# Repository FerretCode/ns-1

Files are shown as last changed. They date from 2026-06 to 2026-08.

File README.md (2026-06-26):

# ns-1

Lo-fi first hardware sampler

# Overview

- Teensy 4.1 based
- 16 Cherry MX switch pads
- 1/4" line in/out
- 3.5mm headphone jack
- 3 rotary encoders for sample editing
- 4 potentiometers for FX control
- Slider for master track volume control
- MicroSD card for loading and exporting samples
- Per-pad looping
- Resampling
- Sampling over USB-C

## Architecture

- The core audio processing functionality is provided by the Teensy 4.1 and its accompanying audio shield (Rev. D)
- Adafruit 1.9" TFT display over SPI
- Line in/out, headphone jack is handled by the audio shield, with volume control in firmware

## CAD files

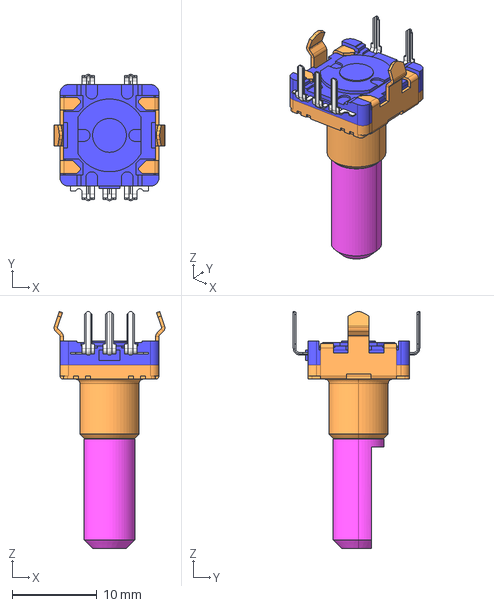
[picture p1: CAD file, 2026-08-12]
hardware/models/ec11e15204a3.stp
13.1 x 15.0 x 28.0 mm

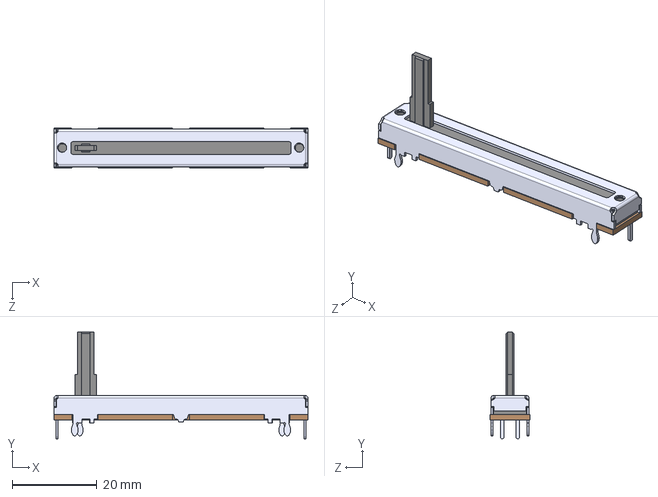
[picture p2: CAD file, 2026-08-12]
hardware/models/PTA4543-2015CPB102.STEP
60.0 x 25.2 x 9.40 mm

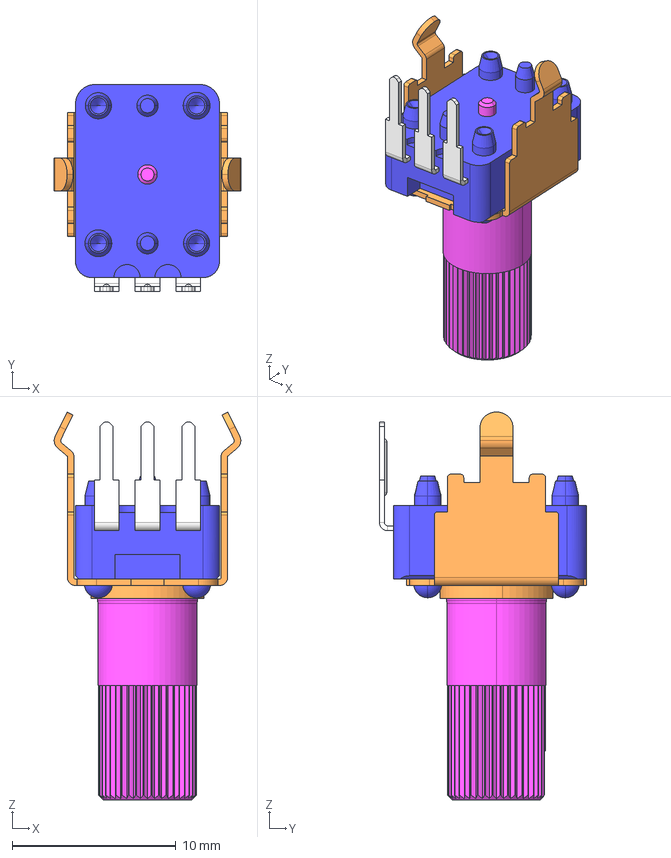
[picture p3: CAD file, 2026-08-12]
hardware/models/rk09k1130a5r.stp
11.4 x 12.7 x 23.7 mm

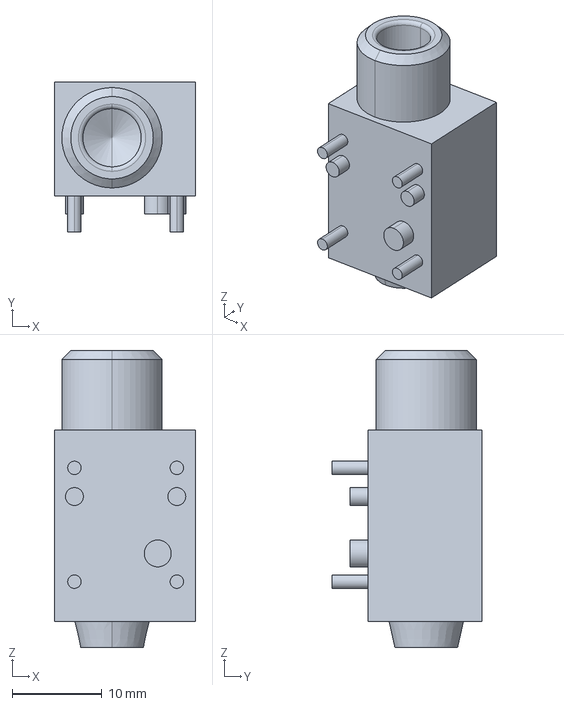
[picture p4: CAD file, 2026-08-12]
hardware/models/nrj4hf-2.stp
15.8 x 16.7 x 33.1 mm

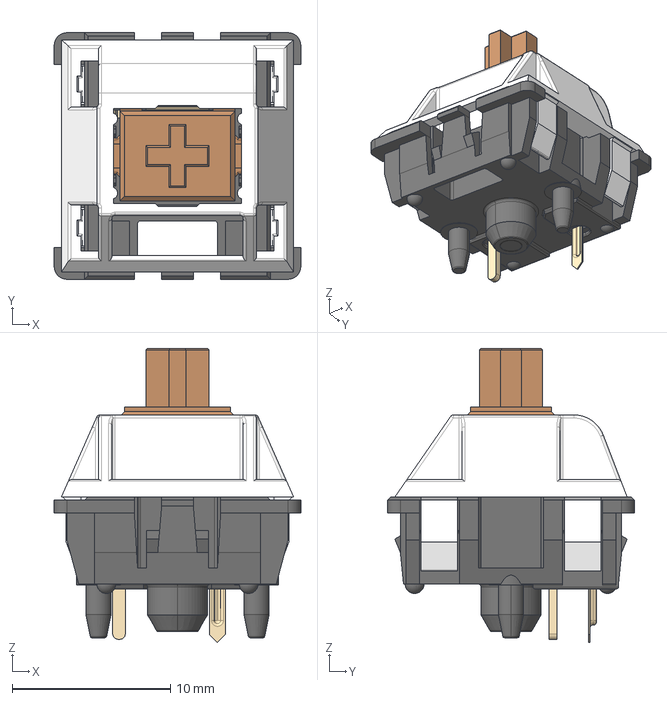
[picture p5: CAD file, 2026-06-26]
hardware/models/MX_PCB.step
15.6 x 15.6 x 18.6 mm

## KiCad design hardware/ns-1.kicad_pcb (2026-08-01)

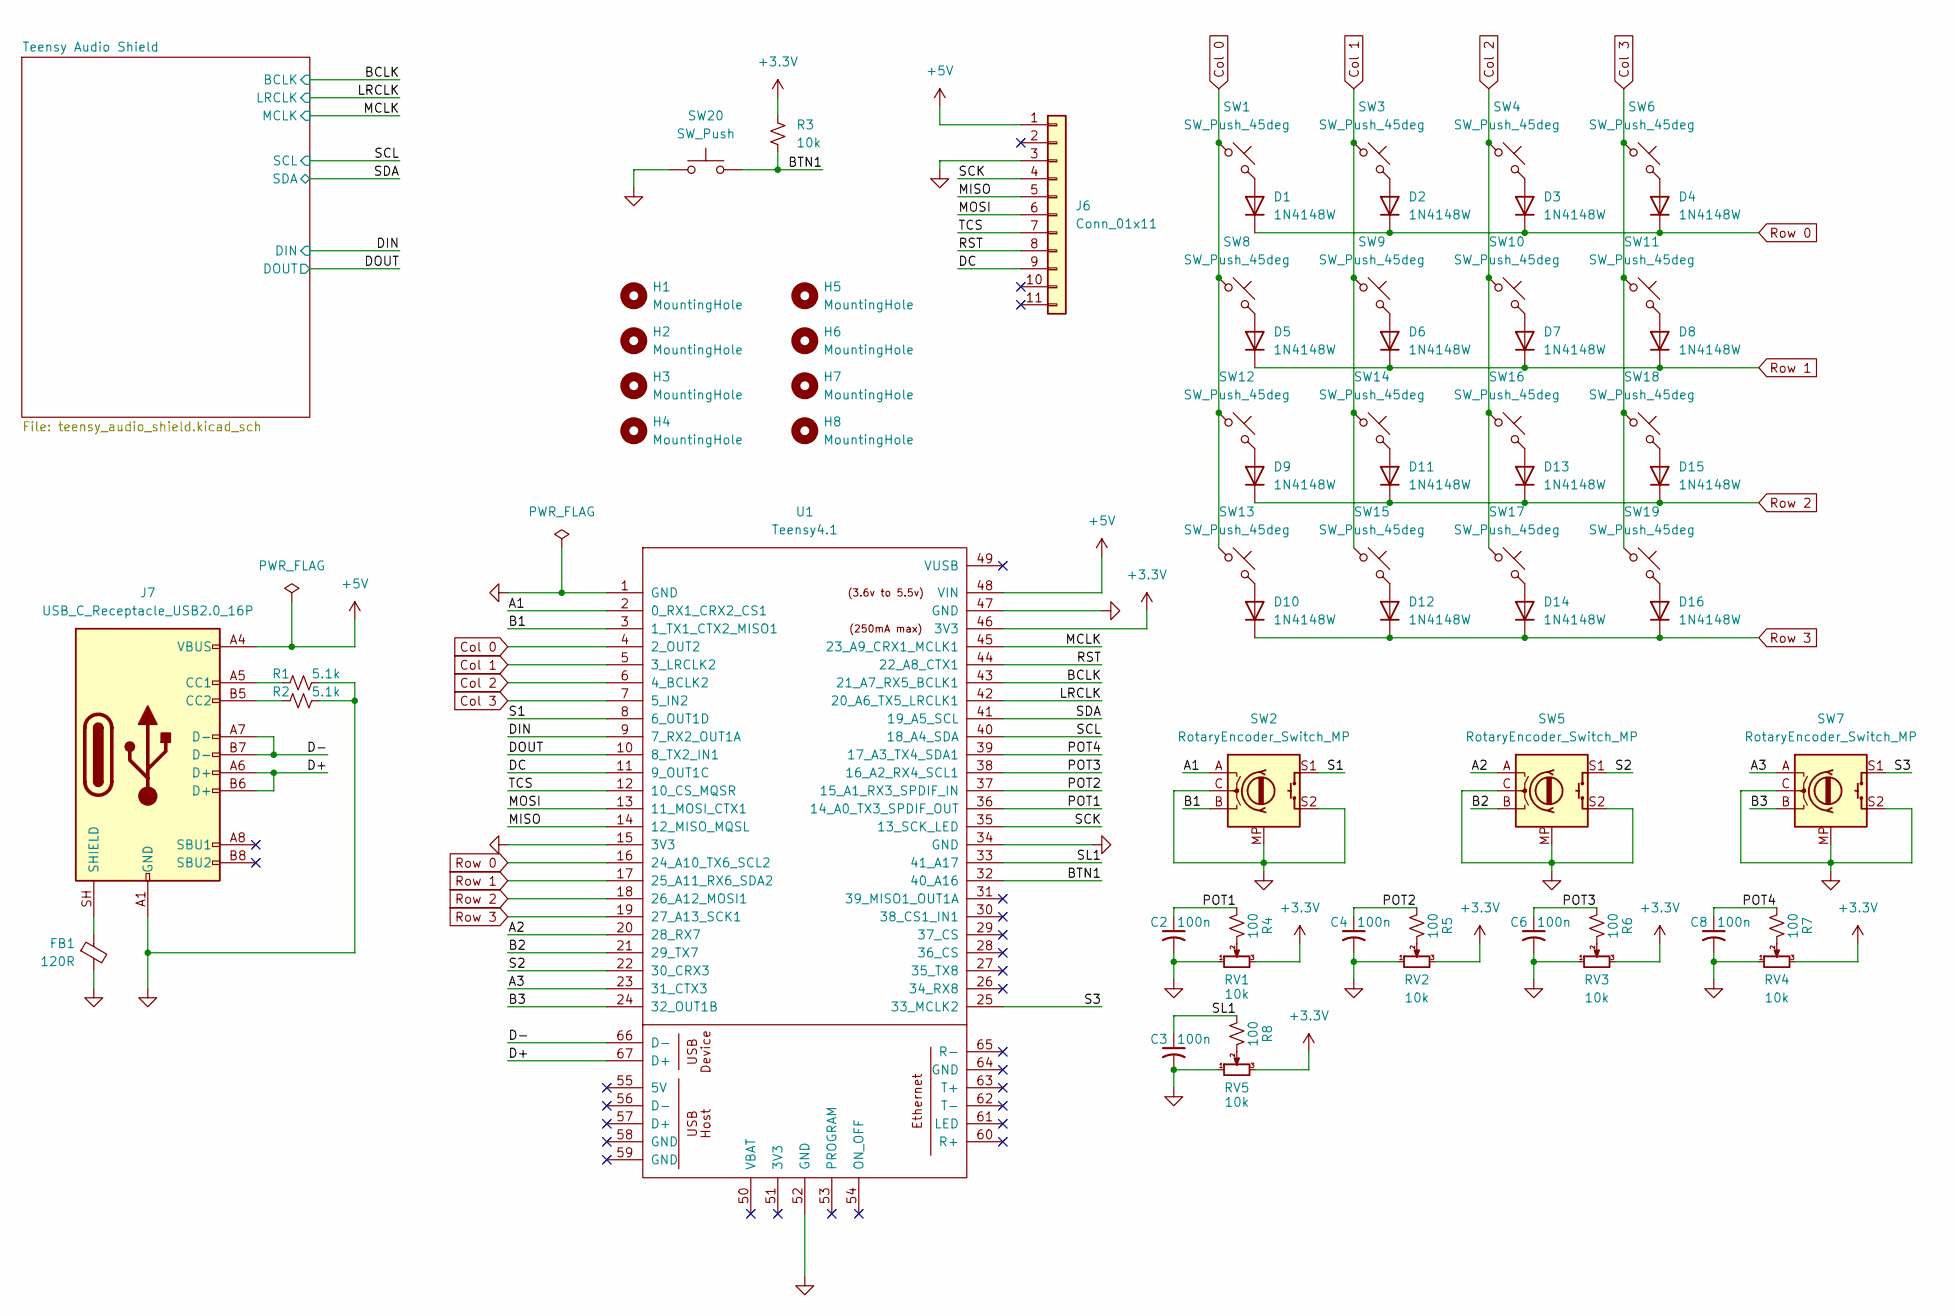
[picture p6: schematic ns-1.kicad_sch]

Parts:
C2, C3, C4, C6: 100n; C_0402_1005Metric; LCSC PN C22435941
C8: 100n; C_0402_1005Metric
D1, D2, D3, D4, D5, D6, D7, D8, D9, D10, D11, D12, D13, D14, D15, D16: 1N4148W; D_SOD-123; LCSC PN C917030
FB1: 120R; L_0805_2012Metric; LCSC PN C2943443
H1, H2, H3, H4: MountingHole; MountingHole_2.5mm
H5, H6, H7, H8: MountingHole; MountingHole_4.5mm
J6: Conn_01x11; PinHeader_1x11_P2.54mm_Vertical
J7: USB_C_Receptacle_USB2.0_16P; USB_C_Receptacle_HRO_TYPE-C-31-M-12; LCSC PN C3197899
R1, R2: 5.1k; R_0603_1608Metric; LCSC PN C2906874
R3: 10k; R_0603_1608Metric; LCSC PN C317926
R4, R5, R6, R7, R8: 100; R_0603_1608Metric; LCSC PN C122970
RV1, RV2, RV3, RV4: 10k; Potentiometer_Alps_RK09K_Single_Vertical
RV5: 10k; Potentiometer_Bourns_PTA4543_Single_Slide
SW1, SW3, SW4, SW6, SW8, SW9, SW10, SW11, SW12, SW13, SW14, SW15, SW16, SW17, SW18, SW19: SW_Push_45deg; SW_Cherry_MX_1.00u_PCB
SW2, SW5, SW7: RotaryEncoder_Switch_MP; RotaryEncoder_Alps_EC11E-Switch_Vertical_H20mm
SW20: SW_Push; SW_Cherry_MX_1.00u_PCB
U1: Teensy4.1; Teensy41

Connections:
+3.3V: R3.1, RV1.3, RV2.3, RV3.3, RV4.3, RV5.3, U1.46 (3V3); also elsewhere on the board
+5V: J6.1, J7.A4 (VBUS), J7.A9 (VBUS), J7.B4 (VBUS), J7.B9 (VBUS), U1.48 (VIN)
/A1: SW2.A, U1.2 (0_RX1_CRX2_CS1)
/A2: SW5.A, U1.20 (28_RX7)
/A3: SW7.A, U1.23 (31_CTX3)
/B1: SW2.B, U1.3 (1_TX1_CTX2_MISO1)
/B2: SW5.B, U1.21 (29_TX7)
/B3: SW7.B, U1.24 (32_OUT1B)
/BCLK: U1.43 (21_A7_RX5_BCLK1); also elsewhere on the board
/BTN1: R3.2, SW20.2, U1.32 (40_A16)
/D+: J7.A6 (D+), J7.B6 (D+), U1.67 (D+)
/D-: J7.A7 (D-), J7.B7 (D-), U1.66 (D-)
/DC: J6.9, U1.11 (9_OUT1C)
/DIN: U1.9 (7_RX2_OUT1A); also elsewhere on the board
/DOUT: U1.10 (8_TX2_IN1); also elsewhere on the board
/LRCLK: U1.42 (20_A6_TX5_LRCLK1); also elsewhere on the board
/MCLK: U1.45 (23_A9_CRX1_MCLK1); also elsewhere on the board
/MISO: J6.5, U1.14 (12_MISO_MQSL)
/MOSI: J6.6, U1.13 (11_MOSI_CTX1)
/POT1: C2.1, R4.2, U1.36 (14_A0_TX3_SPDIF_OUT)
/POT2: C4.1, R5.2, U1.37 (15_A1_RX3_SPDIF_IN)
/POT3: C6.1, R6.2, U1.38 (16_A2_RX4_SCL1)
/POT4: C8.1, R7.2, U1.39 (17_A3_TX4_SDA1)
/RST: J6.8, U1.44 (22_A8_CTX1)
/S1: SW2.S1, U1.8 (6_OUT1D)
/S2: SW5.S1, U1.22 (30_CRX3)
/S3: SW7.S1, U1.25 (33_MCLK2)
/SCK: J6.4, U1.35 (13_SCK_LED)
/SCL: U1.40 (18_A4_SDA); also elsewhere on the board
/SDA: U1.41 (19_A5_SCL); also elsewhere on the board
/SL1: C3.1, R8.2, U1.33 (41_A17)
/TCS: J6.7, U1.12 (10_CS_MQSR)
Col 0: SW1.1, SW8.1, SW12.1, SW13.1, U1.4 (2_OUT2)
Col 1: SW3.1, SW9.1, SW14.1, SW15.1, U1.5 (3_LRCLK2)
Col 2: SW4.1, SW10.1, SW16.1, SW17.1, U1.6 (4_BCLK2)
Col 3: SW6.1, SW11.1, SW18.1, SW19.1, U1.7 (5_IN2)
GND: C2.2, C3.2, C4.2, C6.2, C8.2, FB1.2, J6.3, J7.A1 (GND), J7.A12 (GND), J7.B1 (GND), J7.B12 (GND), R1.2, R2.2, RV1.1, RV2.1, RV3.1, RV4.1, RV5.1, SW2.C, SW2.MP, SW2.S2, SW5.C, SW5.MP, SW5.S2, SW7.C, SW7.MP, SW7.S2, SW20.1, U1.1 (GND), U1.15 (3V3), U1.34 (GND), U1.47 (GND), U1.52 (GND); also elsewhere on the board
unnamed: D1.2 (A), SW1.2
unnamed: D2.2 (A), SW3.2
unnamed: D3.2 (A), SW4.2
unnamed: D4.2 (A), SW6.2
unnamed: D5.2 (A), SW8.2
unnamed: D6.2 (A), SW9.2
unnamed: D7.2 (A), SW10.2
unnamed: D8.2 (A), SW11.2
unnamed: D9.2 (A), SW12.2
unnamed: D10.2 (A), SW13.2
unnamed: D11.2 (A), SW14.2
unnamed: D12.2 (A), SW15.2
unnamed: D13.2 (A), SW16.2
unnamed: D14.2 (A), SW17.2
unnamed: D15.2 (A), SW18.2
unnamed: D16.2 (A), SW19.2
unnamed: J7.A5 (CC1), R1.1
unnamed: J7.B5 (CC2), R2.1
unnamed: FB1.1, J7.SH (SHIELD)
unnamed: R4.1, RV1.2
unnamed: R5.1, RV2.2
unnamed: R6.1, RV3.2
unnamed: R7.1, RV4.2
unnamed: R8.1, RV5.2
Row 0: D1.1 (K), D2.1 (K), D3.1 (K), D4.1 (K), U1.16 (24_A10_TX6_SCL2)
Row 1: D5.1 (K), D6.1 (K), D7.1 (K), D8.1 (K), U1.17 (25_A11_RX6_SDA2)
Row 2: D9.1 (K), D11.1 (K), D13.1 (K), D15.1 (K), U1.18 (26_A12_MOSI1)
Row 3: D10.1 (K), D12.1 (K), D14.1 (K), D16.1 (K), U1.19 (27_A13_SCK1)

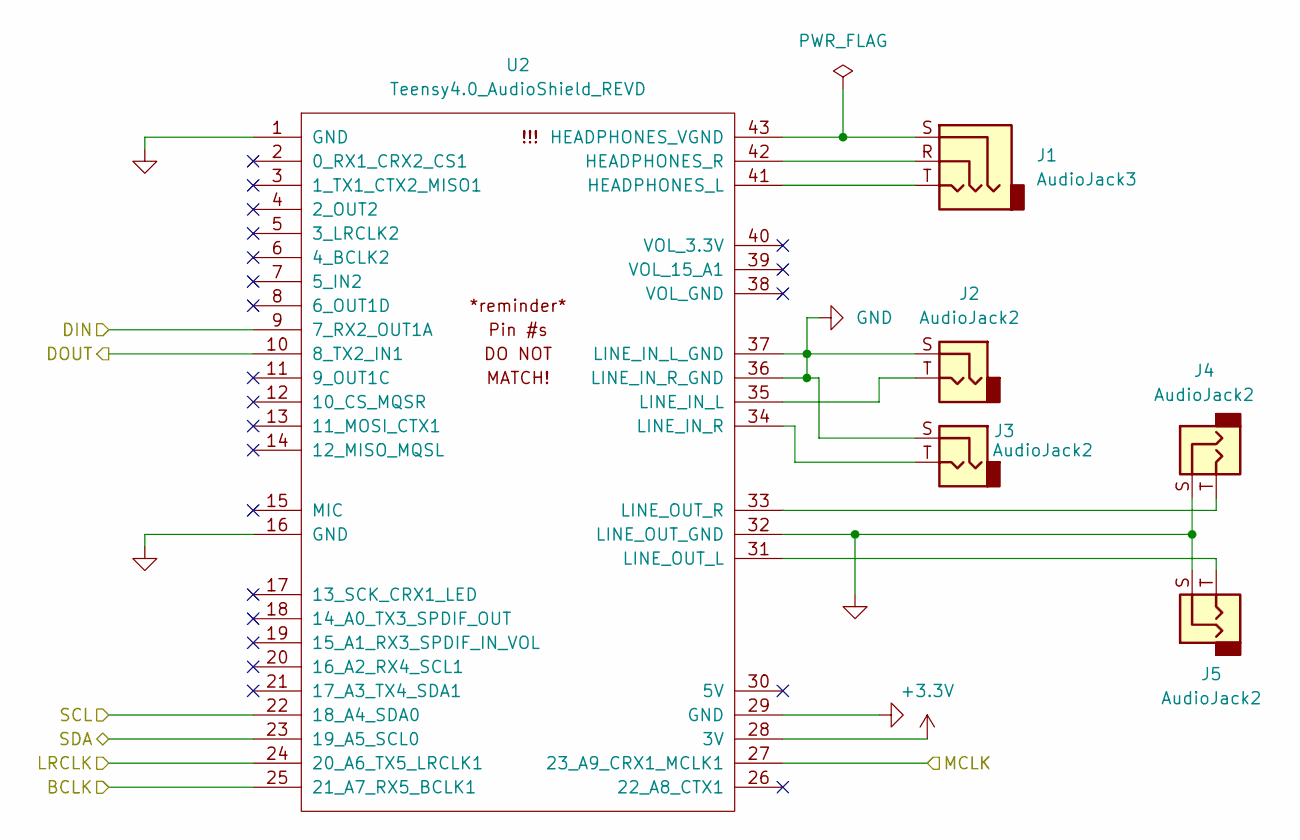
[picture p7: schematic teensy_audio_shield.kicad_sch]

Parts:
J1: AudioJack3; Jack_3.5mm_CUI_SJ1-3533NG_Horizontal
J2, J3, J4, J5: AudioJack2; Jack_6.35mm_Neutrik_NRJ4HF_Horizontal
U2: Teensy4.0_AudioShield_REVD; 4.0audioshield

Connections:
+3.3V: U2.28 (3V); also elsewhere on the board
/BCLK: U2.25 (21_A7_RX5_BCLK1); also elsewhere on the board
/DIN: U2.9 (7_RX2_OUT1A); also elsewhere on the board
/DOUT: U2.10 (8_TX2_IN1); also elsewhere on the board
/LRCLK: U2.24 (20_A6_TX5_LRCLK1); also elsewhere on the board
/MCLK: U2.27 (23_A9_CRX1_MCLK1); also elsewhere on the board
/SCL: U2.22 (18_A4_SDA0); also elsewhere on the board
/SDA: U2.23 (19_A5_SCL0); also elsewhere on the board
GND: J2.S, J3.S, J4.S, J5.S, U2.1 (GND), U2.16 (GND), U2.29 (GND), U2.32 (LINE_OUT_GND), U2.36 (LINE_IN_R_GND), U2.37 (LINE_IN_L_GND); also elsewhere on the board
unnamed: J1.T, U2.41 (HEADPHONES_L)
unnamed: J1.R, U2.42 (HEADPHONES_R)
unnamed: J1.S, U2.43 (HEADPHONES_VGND)
unnamed: J2.T, U2.35 (LINE_IN_L)
unnamed: J3.T, U2.34 (LINE_IN_R)
unnamed: J5.T, U2.31 (LINE_OUT_L)
unnamed: J4.T, U2.33 (LINE_OUT_R)

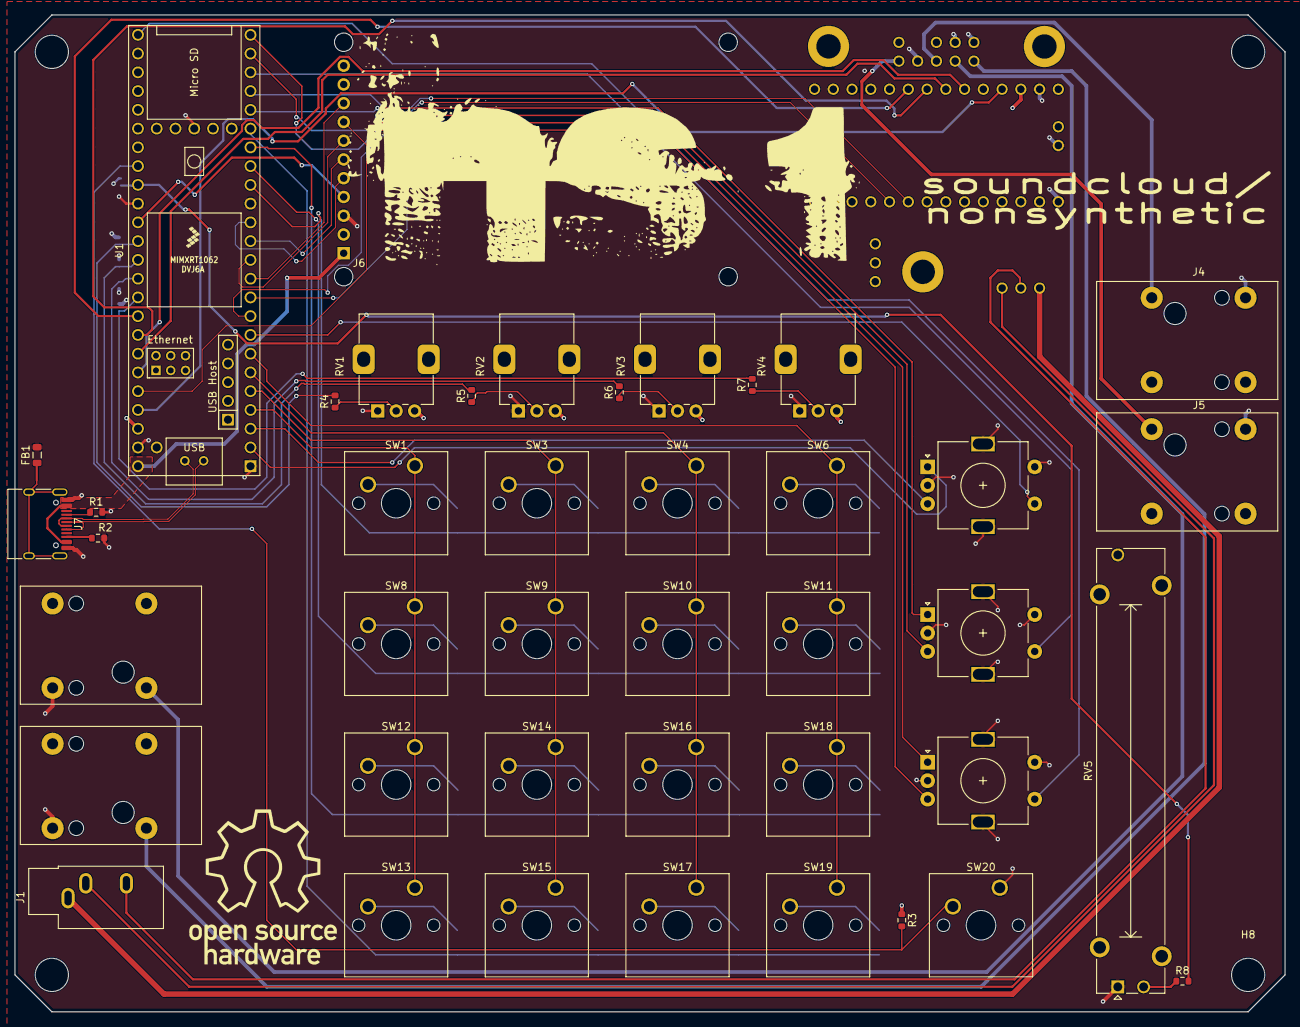
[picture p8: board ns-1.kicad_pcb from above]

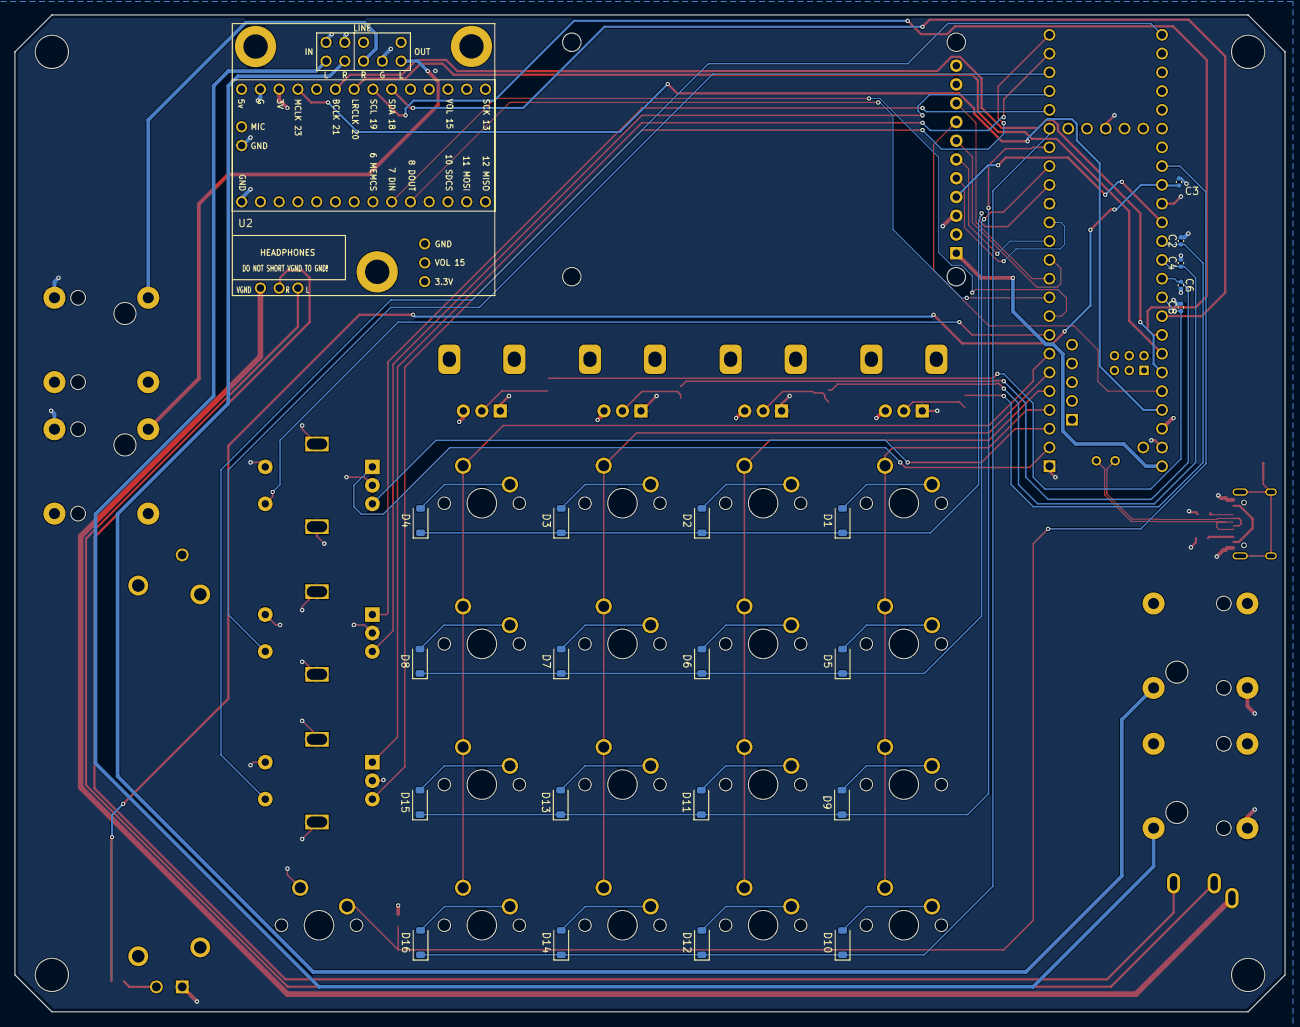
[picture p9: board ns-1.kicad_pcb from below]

Board: 4 copper layers, 172.0 x 135.0 mm, 72 parts (22 on the bottom side), 72 nets.

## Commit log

2026-06-26 add first board revision
    [MX_PCB.step, PTA4543-2015CPB102.STEP, ec11e15204a3.stp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]
2026-08-01 update usb-c footprint
    [ns-1.kicad_pcb, ns-1.kicad_sch, production_bom.csv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]
2026-10-28 start respin to stm32h7
2026-10-29 reorganize and finish codec / power
